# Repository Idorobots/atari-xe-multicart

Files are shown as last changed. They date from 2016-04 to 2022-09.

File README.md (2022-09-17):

# XE Multicart

A multi-game cartridge for the Atari 400/800/XL/XE with software game selection which can hold up to 127 games!

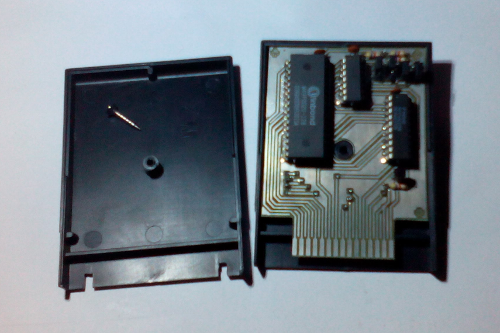
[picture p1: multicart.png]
multicart
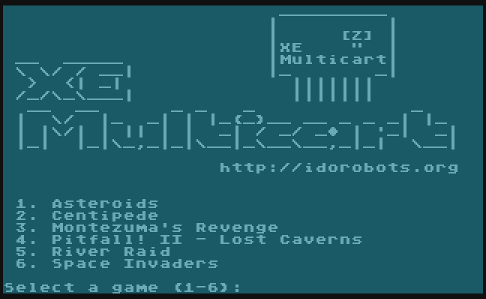
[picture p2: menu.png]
menu
 

# How it works?

A `74HCT373` latch is used for extra address pins, it's accessed by writing to the cartridge control block (`$DF00`) causing a bank switch. After selecting appropriate ROM bank, the firmare resets the console in turn starting the game. To select another game, reboot your Atari.

# Assembly instructions
## PCB
Assuming that you already have the PCBs on hand, either by ordering them on-line or creating them yourself, the assembly is pretty simple - just solder the `74HTC373` latch, the transistor and the passive components. It is highly recommended to solder a socket for the memory chip as it makes it much easier to re-program it. **Also, keep in mind that the component side goes into the console facing down, so prepare your case accordingly.**

## Memory chip configuration

The PCB layout of this cartridge is customizable - you can fit any 28/32-pin JEDEC-compliant EPROM chip in the `27C` line or compatible flash memory chip with size ranging from as low as 64 kbit up to 8 mbit. Fitting larger chips means you will be able to store more game ROMs (up to 127 total), but you can also use this layout without the game selection firmware to store any single standard 8k/16k game you want.

### Jumper settings

There are four jumpers on the PCB - `JP1` to `JP4` - oriented vertically when looking at the top layer with the edge connector facing down:

```
      0   0   0   0\ UP
DOWN /0   0   0   0/
     \0   0   0   0
     JP1 JP2 JP3 JP4
```

These are used to configure the cartridge for the appropriate memory chip. The following table lists jumper settings for various common configurations (UP means "short top two pins", DOWN means "short bottom two pins" and X means "don't care"):

| Memory chip size | JP1  | JP2  | JP3  | JP4  |
| --- | ---- | ---- | ---- | ---- |
| 64k (27C64) | X | X | UP | UP |
| 128k (27C128) | X | X | UP | UP |
| 256k (27C256) | X | X | UP | DOWN |
| 512k (27C512) | X | X | UP | DOWN |
| 1m (27C010) | UP | UP | X | DOWN |
| 2m (27C020) | UP | UP | DOWN | DOWN |
| 4m (27C040) | UP | DOWN | DOWN | DOWN |
| 8m (27C080) | DOWN | DOWN | DOWN | DOWN |

## Building the firmware
### Prerequisites
To succesfully build the firmware for the multicart, you will need to set up the following dependencies on your system:
- `make` - the Make build system,
- `python3` - Python programming language version 3.*,
- `gcc` - GNU Compiler Collection,
- `cc65`- the [CC65 compiler](https://cc65.github.io/).

### Build
In order to build the firmware & a cartridge image you will need some standard 8k/16k ROM files (obtainable freely on the Internet). Install all the dependencies, put your ROMs into the `roms/` directory and type:

```
make
```

This will run a script that automatically detects and arranges the games, builds the firmware and compiles a cartridge image ready for burning with your favourite EPROM burner.

Alternatively, you can supply a custom ROMs directory like this:

```
make ROMS=path/to/roms/directory
```

If you encounter any troubles while building, make sure to rebuild everything cleanly:

```
make clean && make
```
## Building from a docker container

In order to build the container itself run the following command in project directory

```
docker build -t atari_xe_multicart:latest .
```

After the container is ready to use run the following command to create `cart.bin` file. It assumes that .rom files are inside the /roms directory inside project directory.

```
docker run -ti --rm -v $(pwd)/roms/:/input/ -v $(pwd):/output/ atari_xe_multicart
```

# Running in an emulator

Multicart images don't work in any emulators that I know of, because they are using a custom (if simplistic) bank-switching mechanism. For testing purposes, you can run just the `menu.bin` (the game selection firmware) by loading it as a standard 8k cartridge ROM in your favourite Atari 800/XE emulator. For example:

```
atari800 -xl -xlxe_rom path/to/ATARIXL.ROM -cart menu.bin
```

It'll display the game selection menu, but any attempts at selecting a game will result in restarting the game selection menu.

# License

Software & hardware licensed under the MIT license (see LICENSE file for details). The OSHW logo comes from the [BFL library](http://www.baconfatlabs.com/2011/11/oshw-eagle-symbols-for-schematic-and-silkscreen/), licensed under CC-BY-SA. Any commercial product names seen on software screenshots are for demonstration purposes only and are not included with this product.

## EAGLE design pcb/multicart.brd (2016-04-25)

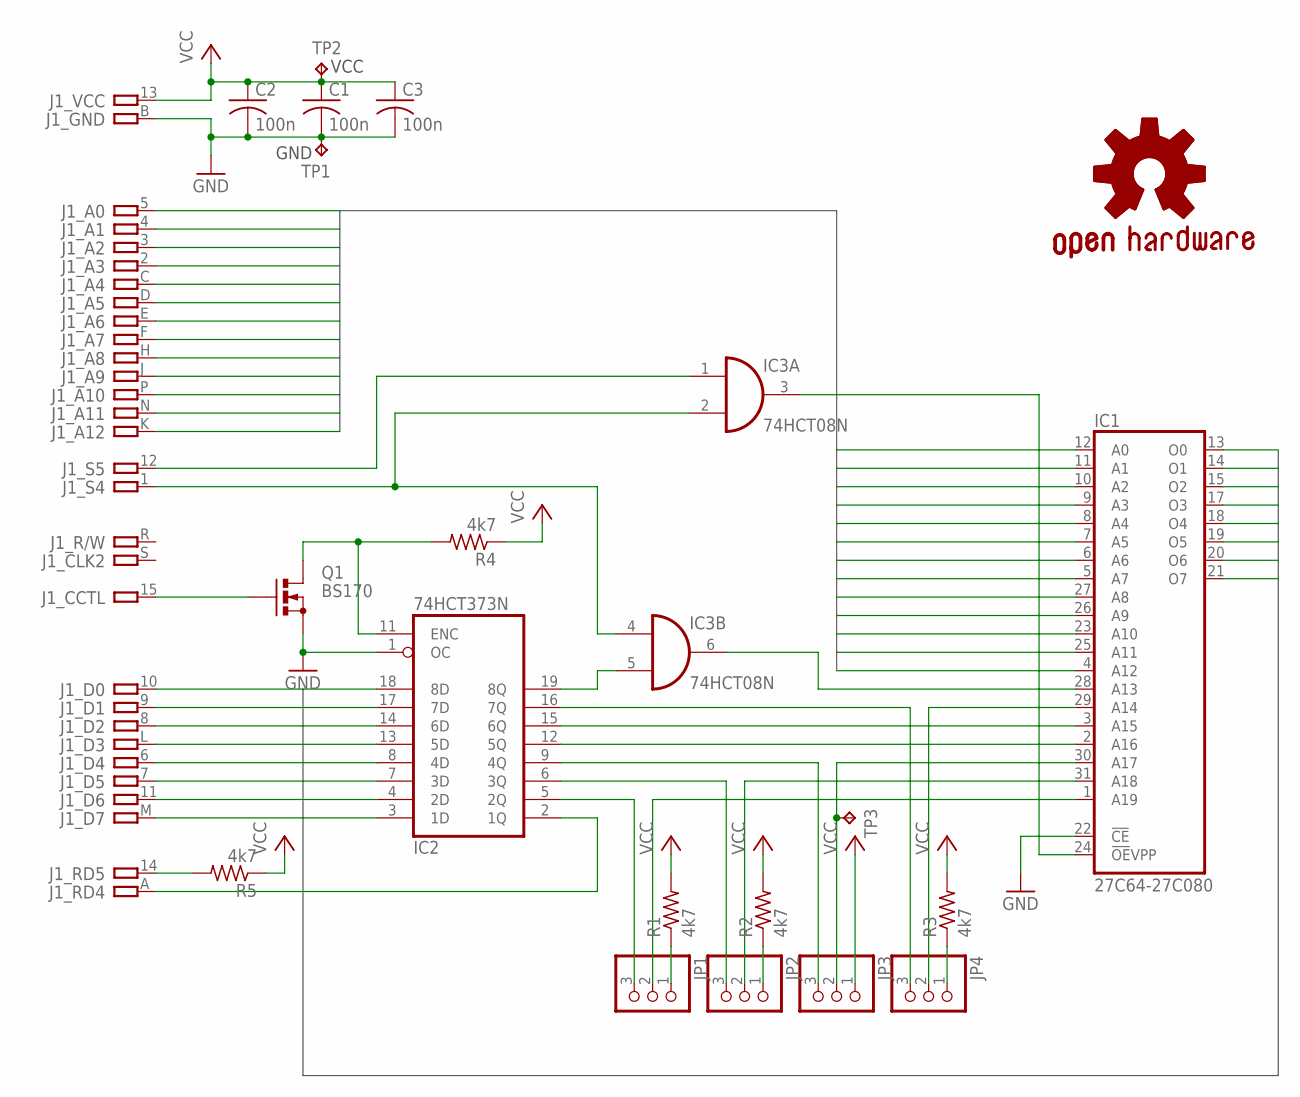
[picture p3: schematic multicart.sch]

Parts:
C1, C2, C3: 100n; C025-025X050
GOLD_ORB_SM1: OSHWLOGO_GOLD_ORB_SM; OSHW2
IC1: 27C64-27C080; DIL32
IC2: 74HCT373N; DIL20
IC3: 74HCT08N; DIL14
J1: ATARI-800
JP1, JP2, JP3, JP4: PINHD-1X3; 1X03
Q1: BS170; SOT54E
R1, R2, R3, R4, R5: 4k7; 0204/7
TP1, TP2, TP3: TPB1,27; B1,27

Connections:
A0: IC1.12 (A0), J1.5
A1: IC1.11 (A1), J1.4
A2: IC1.10 (A2), J1.3
A3: IC1.9 (A3), J1.2
A4: IC1.8 (A4), J1.C
A5: IC1.7 (A5), J1.D
A6: IC1.6 (A6), J1.E
A7: IC1.5 (A7), J1.F
A8: IC1.27 (A8), J1.H
A9: IC1.26 (A9), J1.J
A10: IC1.23 (A10), J1.P
A11: IC1.25 (A11), J1.N
A12: IC1.4 (A12), J1.K
D0: IC1.13 (O0), IC2.18 (8D), J1.10
D1: IC1.14 (O1), IC2.17 (7D), J1.9
D2: IC1.15 (O2), IC2.14 (6D), J1.8
D3: IC1.17 (O3), IC2.13 (5D), J1.L
D4: IC1.18 (O4), IC2.8 (4D), J1.6
D5: IC1.19 (O5), IC2.7 (3D), J1.7
D6: IC1.20 (O6), IC2.4 (2D), J1.11
D7: IC1.21 (O7), IC2.3 (1D), J1.M
GND: C1.2, C2.2, C3.2, IC1.16 (GND), IC1.22 (!CE), IC2.1 (OC), IC2.10 (GND), IC3.7 (GND), J1.B, Q1.S, TP1.TP
unnamed: IC2.19 (8Q), IC3.5 (I1)
unnamed: IC2.16 (7Q), JP4.3
unnamed: IC1.3 (A15), IC2.15 (6Q)
unnamed: IC1.2 (A16), IC2.12 (5Q)
unnamed: IC2.9 (4Q), JP3.3
unnamed: IC2.6 (3Q), JP2.3
unnamed: IC2.11 (ENC), Q1.D, R4.2
unnamed: J1.15, Q1.G
unnamed: JP1.1, R1.1
unnamed: IC1.31 (A18), JP2.2
unnamed: JP2.1, R2.1
unnamed: IC1.30 (A17), JP3.2, TP3.TP
unnamed: IC1.1 (A19), JP1.2
unnamed: IC2.5 (2Q), JP1.3
unnamed: IC1.29 (A14), JP4.2
unnamed: JP4.1, R3.1
unnamed: J1.14, R5.2
unnamed: IC3.1 (I0), J1.12
unnamed: IC3.2 (I1), IC3.4 (I0), J1.1
unnamed: IC1.28 (A13), IC3.6 (O)
unnamed: IC2.2 (1Q), J1.A
unnamed: IC1.24 (!OE!VPP), IC3.3 (O)
VCC: C1.1, C2.1, C3.1, IC1.32 (VCC), IC2.20 (VCC), IC3.14 (VCC), J1.13, JP3.1, R1.2, R2.2, R3.2, R4.1, R5.1, TP2.TP

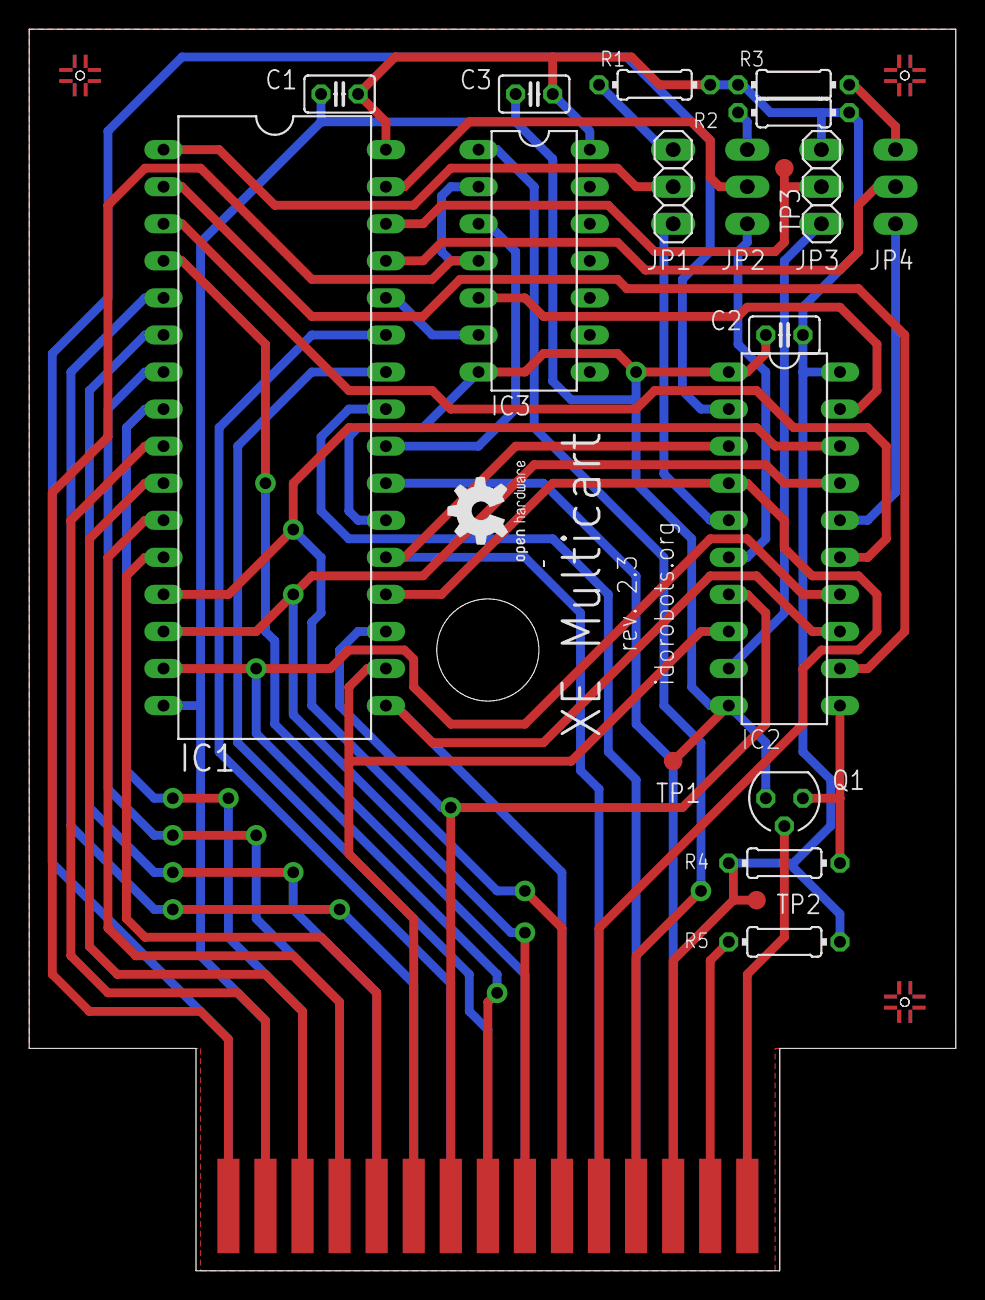
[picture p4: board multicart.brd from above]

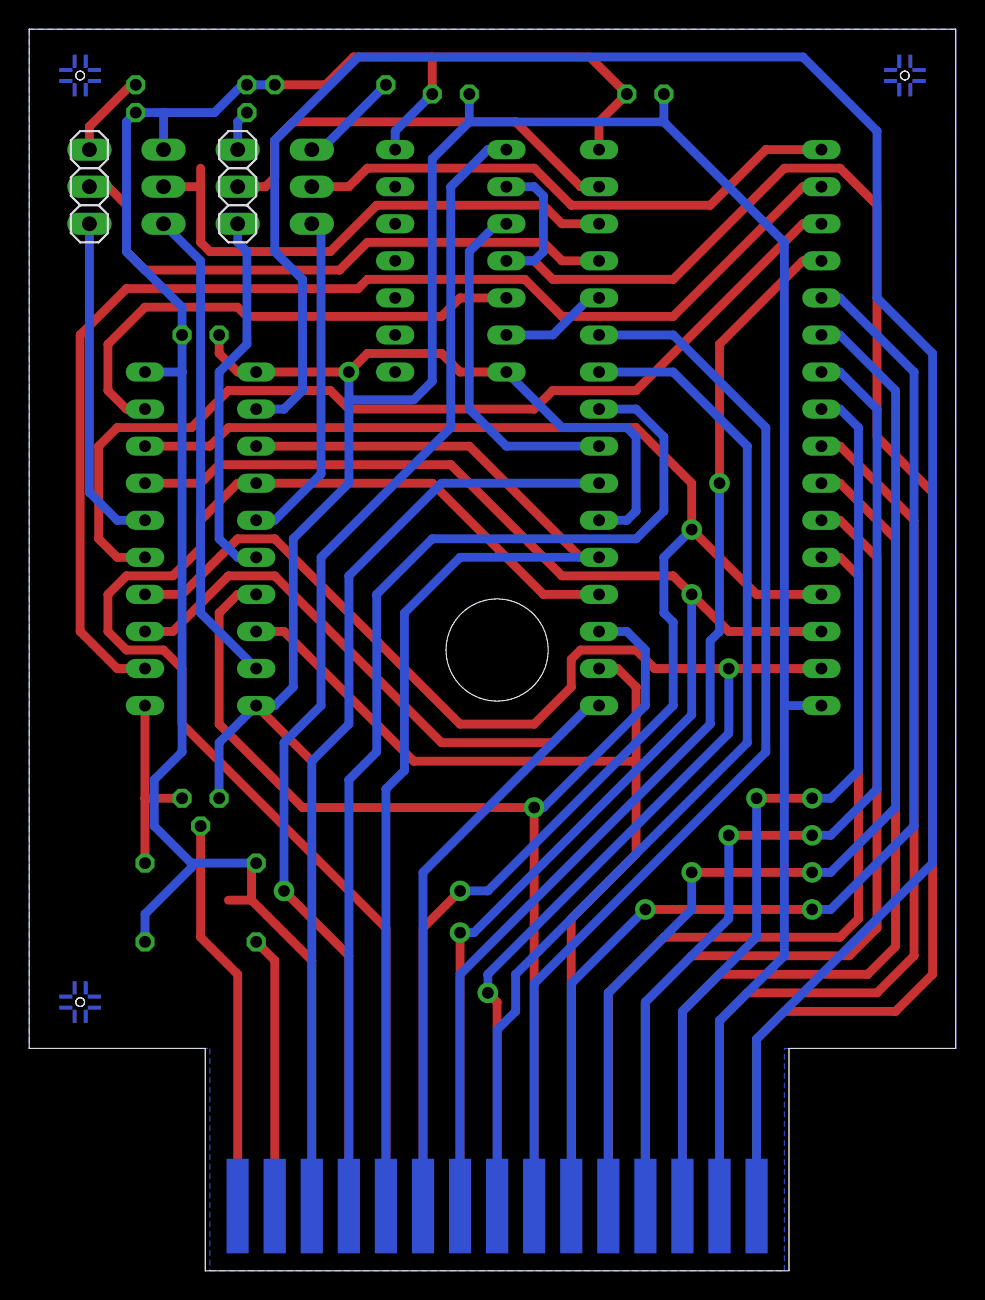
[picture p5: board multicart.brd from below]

Board: 2 copper layers, 63.5 x 85.1 mm, 27 parts (5 on the bottom side), 45 nets.

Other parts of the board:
U$1, U$2, U$3, U$4, U$5, U$6: PASSER-HOLE

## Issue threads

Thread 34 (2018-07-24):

How to setup 27c512 ?

emartisoft, 2018-07-24:
Hi,
I wanted to use 27c512 but how to setup it on pcb. Please look at the my uploaded picture. Is this true? I created 64 KB bin file on linux via make command. I tried it on 600xl and 800xl but it does not work.

How to do? What stage could I have done wrong?

http://i64.tinypic.com/2nip4s7.jpg

Idorobots, 2018-07-26:
Hi,

The setup looks good, that should result in a 512k multicart and assuming that the bin file begins with the game selection firmware it should work on any XE-series machine. Not sure about XL as these probably use a slightly different OS ROM, which the game selection firmware kind of takes for granted right now.

Does it display anything when you put the multicart into the console? Can you try burning an 8k game to the very beginning of the flash chip, so that it acts as the selection firmware? If that does work it's probably the firmware that needs some adjustments. Unfortunately, I don't have any non-XE Atari machines to test in on :(

You can also try fiddling with the jumpers, basically any setup should at least display the game selection firmware, so if that doesn't change anything it's probably something different.

Also, a silly question - are you inserting the multicart into the console correctly? It should go there component side down (a bit counterintuitive, I know).

Idorobots, 2018-07-26:
I just realized that the staged photo is misleading as it looks like the component side goes on top, not the bottom. I'll make that explicit in the README.

emartisoft, 2018-07-26:
Hi again,
Thank you firstly. As I said, I tried & tested it on ATARI 800XL & 600XL but not XE series :(

I burned 8K rom file (for Your menu.rom and a few 8k game rom file) on M27C64A. I tested it all. When I put the cart into the console, It displays like my uploaded photo image.

_Image Links:_
I. http://i68.tinypic.com/34ye83d.jpg
II. http://i63.tinypic.com/289g552.jpg

If I insert the multicart into the console wrongly, It boots BASIC, It says READY. :)

As a result should we say that it does not work for XL?

Idorobots, 2018-07-27:
That might indeed be the case here, unfortunately.
It's hard for me to say what might be the issue here without hooking up a signal analyser to the cart, so I can't recommend anything other than maybe reflowing all connections on the cart PCB and cleaning the cart slot contacts on the console. I did get a lot of odd behaviour resembling your second picture in the previous reply when building this thing - the problem was bad connections between the thin PCB of the multicart and the cart slot on my Atari. So maybe that's indeed the case here? A 1.6 mm thick PCB should be fine, but maybe you've ordered 0.8 mm?

Idorobots, 2018-07-27:
Looking at my old version in the picture in the README I actually went for using an HC series 74373 latch instead of a TTL one. I don't really remember that changing much, but since I left out any pulldowns on the extra address lines comming from the 74HCT373 it might be the root cause of the issue - the lines aren't all zeros making it select one of the ROMs already. Potentially a non-existant one or the wrong half of one of them. Maybe try changing that for a 74HC373 instead? I'm also using a TTL 7408 and the transistor is a BS107.

emartisoft, 2018-07-27:
I have ordered 1.6 mm thick PCB. I will reflow all connections on the cart PCB and cleaning the cart slot contacts on the console.

I will try 74HC373. But You said that transistor is a BS107. **It is BS170, isn't it?**
If I change from 74HCT373 to _74HC373_, Should I use _TTL 7408_ and _BS107_?

Idorobots, 2018-07-27:
On the working cart I have a `74HCT08`, `74HC373` and `BS107`, but the `BS170` should do equally fine. I don't have a `74HCT373` on hand right now, so I can't really test if that causes the odd behaviour. I suppose it would be wise to add the pulldowns to the design regardless.

emartisoft, 2018-07-27:
Hmmmm. I also will try `74HCT08`, `74HC373 `and `BS107`. I'll return feedback to you.
In addition, Is **LS** (`74LS08`, `74LS373`) slow or compatible for this project?

emartisoft, 2018-08-01:
I tried LS but it does not work. :(

Idorobots, 2018-08-01:
Then the HCT probably won't work either. That's a pickle, as I can't really reproduce the problem on my end, so I can't really debug it. All I can think of doing is hooking a logic analyser to the extra address lines to verify wether the transitions are correct.

LessNick, 2022-03-23:
Hello there ;)

Finally, I finished soldering my board and I also have questions.

I also want to use the w27c512 chip, but I have questions about how to place the chip in the socket?
Unfortunately, the links to the photos of the topikstarter are no longer available, and the answers did not bring clarity.

Since it is correct to place the chip in the socket, from the beginning of the contacts or from the end?

Here my photos: https://imgur.com/a/wgHHUli

Also, do I understand correctly that you need to insert the cartridge into the atari with the chips down?

I absolutely don't mind if you add my photos to the project so that in the future people can get visual information right away.

Thank you very much in advance!

Idorobots, 2022-03-26:
Hi, sorry for the late answer.
The chips supported are conformant to the JEDEC pinout standard, meaning you can align them towards the bottom of the socket (away from the notch). Then you have to set up the jumpers accordingly (it's described on the README) in order to supply the power to the chip.
If you're unsure how to align the chip, you can follow the pinout on the biggest one supported ([see this datasheet](https://pdf1.alldatasheet.com/datasheet-pdf/view/56131/ATMEL/27C080.html) and align the GND & Output3 pins on your chip with the socket.

LessNick, 2022-03-26:
Oh! Thanks for anwser! As I understand it, this is the same principle as in the programmer. There, too, the chip is aligned to the bottom of the connector.

Like on this photo → https://imgur.com/a/GS2mEZp

Pins set for 512Kb:

Memory chip size | JP1 | JP2 | JP3 | JP4
512k (27C512)    |  X  |  X  | UP  | DOWN

The question of how to correctly insert an atari cartridge also remained open. Is the previous photo correct?

Location down the chips → https://imgur.com/a/wgHHUli

Idorobots, 2022-03-26:
Looking good! According to the README the component side is supposed to face down when inserted into the console. I'm inclined to believe that's correct :D

LessNick, 2022-03-26:
Unfortunately, the board didn't work :( Atari starts polling devices and freezes. If the cartridge is removed, atari start BASIC.

How i understand that when start the cartridge, there should be no device polling. Just starts the code from cartridge?

Idorobots, 2022-03-26:
Yup, it should run the cart code instead of basic. I had some contact issues initially, because my PCB was too thin. You might wanna check the connections on yours. In my case, either bending some of the Atari edge connector pins or slightly tinning the contacts on the multicart was what did the trick.

LessNick, 2022-03-26:
Ah, here's the thing. Thanks a lot. I'll check the contacts on atari.

gadiscz, 2022-04-06:
Hi, I have the same problem. I have an Atari 800 XL. I made a XE Multicart cartridge (27C512), I did everything according to the instructions, but my menu doesn't appear and I just run basic READY.   :-(
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
LessNick, 2022-04-06:
Unfortunately, cartridge has not start. I cleaned the contacts on the atari side. Distinct black traces of oxides remained on the paper. I ordered the board on allpcb.com and its thickness is really 1.6mm.

The ROM chip is working, it can be flashed and read without problems.

There are only two questions left, these are the other chips themselves, perhaps the Chinese sent low-quality components. And secondly, capacitors near chips confuse me a little. If I understand correctly, this is for more stable works of chips and capacitors should not be polarized?

Judging by the scheme, they can be both polarized and fixed. I use fixed.

gadiscz, 2022-04-06:
I have a thickness of 1.6 mm. other original old cartridges work for me. I will try another EPROM size

LessNick, 2022-04-06:
>I will try another EPROM size

Hmm... maybe that's really the problem. Looking forward to the result :)

Idorobots, 2022-04-06:
> If I understand correctly, this is for more stable works of chips and capacitors should not be polarized?
These are bypass caps, they indeed make for a stable power supply for those chips. You can use small-value tantalums or ceramics for these, the values don't really matter so anything from 1nF to 100nF should be good enough.

> I have a thickness of 1.6 mm.
Hmm, then it's going to be the multicart indeed. Please check the 7408 next, that one is used to determine whether the EPROM should be enabled and which address to choose for it. If that works correctly then it means the EPROM is not floating, so it should at least execute something other than BASIC (even if it's some garbage).
Another thing to check is the MOSFET inverter on the CCTL line, that controls the bank selection. If that is stuck in either state (due to a different pinout of the part you used for your multicart, or some such problem) it might cause the data lines to be pulled high or low and that might mess it up (although I would expect it to execute some garbage instead of BASIC if that were the case).
Lastly, it might be the software. AFAIR, I'm doing some "sanity checks" to figure out if the console was soft-rebooted to start a new game - poking around the OS memory to check some values in memory. Perhaps that is triggered by the menu immediately due to a different OS version than the one I implemented it on. You can try programming the EPROM with just one game at the very start of the EPROM (so instead of the game selection menu) and try the multicart this way. If that's it, then we'll need to figure out how to update sanity checks for different OS versions.

gadiscz, 2022-04-06:
Ok I'll try to upload one file. How do you convert .xex files that are different size 6-40kB to the correct size (8-16kB)?

LessNick, 2022-04-06:
>How do you convert .xex

No no! XEX file will not work, you need to take a ready-made BIN file, not even CAR (it has a header at the beginning of the file)

LessNick, 2022-04-06:
I report. I flashed one image of the Boulder Dash cartridge in W27c512 - the result is the same, that is, none.

Then I found very old chips with ultraviolet erasure 27c512, 27c256 and 27c64. I did not try to flash them, since they must first be washed with an ultraviolet lamp. I just plugged it in for a test, setting the jumpers according to the diagram.

256 and 512 the result is the same as with rom image. But 27s64 began to flickering the screen, then purple then black. That is, it looks like something is still trying to start.

A little later I will try to erase the chip with ultraviolet light and re-flash it.

LessNick, 2022-04-06:
I also tried to run without a ROM, the result is the same, nothing happens. It is very likely that some components of scheme do not work and the ROM chip does not turn on correctly.

I would venture to suggest that for 27c64 such switches are not critical and it is trying to start.

gadiscz, 2022-04-06:
What program do you use to convert xex to rom? Do you need to enlarge a file that has 15kB to 16kB?

gadiscz, 2022-04-06:
I have this working but only with their file...

[https://www.pcbway.com/project/shareproject/ATARI_800XL_MULTI_GAME_CARTRIDGE__4_x16KB_.html](url)

gadiscz, 2022-12-21:
finally i bought an atari 800XE but the problem is not solved :( still my bin files don't work. i have different eproms do you have a working bin file for test?

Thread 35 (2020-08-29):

Cart detection

dikdom, 2020-08-29:
Hello,
could you please describe how an Atari XL/XE detects if a cart is present in the system? I thought it triggers a low /S4 and checks if RD4 is high (and respectively triggers /S5 and checks RD5) but in this case the 373 provides random output after poweron, so it should not work... 👍  (but it does at your end).

Thanks!
Erm... RD5 is always set high, so I guess the machine triggers /S5 and RD5 is high -> cartridge is present.

Idorobots, 2020-08-29:
Hi, indeed, whenever the cart is in the slot it'll register as present. The 373 goof up is known, surprisingly I had some good luck with TI parts always coming on in a known state, so I never noticed that originally. I don't have an Atari on hand these days, so I never bothered fixing the issue. :) A generally better idea would be to use a latch with master reset, as to ensure a proper state after startup.

Closed 2020-08-29.

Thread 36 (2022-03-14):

Emulation support

LessNick, 2022-03-14:
Hello.

At my request, Beta version of Altirra now supports "xe-multicart".

I created two cartridges with 8k games and 16k games.

In the first case (8k) everything works fine. But the cartridge with 16k games could not be start. The emulator crashes or atari show self test. Unfortunately, Unfortunately, I'm only in the process of soldering a hardware cartridge so far and can't test rom image at the real atari.

So far, of course, this is still only a beta version, but it is already gratifying that you can test the assembly before flashing the chip.

Perhaps this is some kind of flaw in the emulator, or perhaps I have not assembled something correctly.

In any case, I wanted to inform you about this wonderful news. As soon as full-fledged work in the emulator is implemented, it will be possible to update the documentation.

Link to the post

https://atariage.com/forums/topic/327133-altirra-400-released/?do=findComment&comment=5021103

Idorobots, 2022-03-14:
Hi,

This is as much a good news as it is surprising, since this project has been pretty inactive for the past few years. :)
If I remember correctly, the 16k games need to be aligned a certain way in order to load correctly (essentially, both 8k halves have to occupy the right memory locations). That alignment is supposed to be done by the packing scripts provided in this repository, but I've got to admit that I haven't tested them thoroughly - I made some carts with the games I like the most and that seems to be working on both of my machines.
Would you like to become a contributor to this repository? I currently don't have the time to maintain it, and it seems like the Atari community is actually using this thing. :)

LessNick, 2022-03-14:
Well, at the moment I'm interested in this project. I ordered PCBs and plan to solder a few pieces. In any case, if there are any improvements or changes in the code, I will definitely send you :)

LessNick, 2022-03-14:
I was able to find the pattern of the error.

If you arrange the blocks like this:
8k menu
8k first game
16k second game

For example, pac-man = 8k. zaxxon = 16k
Everything works perfectly.

I think we need to rewrite a bit the logic of the collector in accordance with this idea.

By the way, another passing question, cartridges with a volume of more than 16k, for example 32k, is not really possible to combine at all?

Idorobots, 2022-03-14:
Hey,

Hmm, yeah, I think the menu needs to be on one of the slots during boot so the other one cannot be taken by a 8k game, if the first game is 16k it skips that slot so it's all fine.

32k carts use a mapping scheme of their own as the Atari only has two cart slots 8k memory each. 8k games can go into either of the slots, while the 16k games occupy both of these. The bigger carts need some extra hardware to switch different parts of the cart in and out onto these two slots (much like the XE multicart does it). I don't think the scheme I chose is compatible with any existing cart designs (this project started on a weekend, so I didn't do much research). :)
I think with some hardware modifications it should be possible to make it compatible with at least some cart types - AFAIR the XEGS cart for instance follows a similar bank switching scheme.

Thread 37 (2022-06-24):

How to generate the compiled bin to program?

repetto74, 2022-06-24:
Hi,
I am struggling in trying to understand how to generate a compiled bin file with my rom selections and menu.
I am using Windows10 and try to use "make" command from the console but it does not work. I tried with buildcart.py and I get the message that no roms have been found despite 8k and 16k roms are copied in the roms folder.
Is there a more detailed guide on steps to perform here? What need to be installed?
Thanks
Rick

Idorobots, 2022-06-25:
Hi, I don't currently have access to any windows machines, but if memory serves me right, there were pre-made unix-like development environments available for Windows. MinGW and Cygwin are two such examples, but there is also the newly added Windows Subsystem for Linux that should also support makefiles via an external program (see [here for more info]( https://stackoverflow.com/questions/32127524/how-to-install-and-use-make-in-windows)).
Once you have either of those set up, it should be a matter of just placing your ROM files into the `roms` directory and then running the make command.

repetto74, 2022-06-25:
Hi Idorobots,
Thank you for your reply :-). I will give a look to your link at try to figure out how to install a proper working environment to compile under Windows 10.
Have a good day!
Rick

repetto74, 2022-07-01:
I have installed Make on Windows 10. When I try to compile I get this message from the CMD console:
```
C:\Users\RICCARDO REPETTO\Desktop\atari-xe-multicart-master>make clean && make
rm -f src/games.c
process_begin: CreateProcess(NULL, rm -f src/games.c, ...) failed.
make (e=2): Le fichier spécifié est introuvable. --file not found--
make: *** [clean] Error 2
```
What am I doing wrong here?

Idorobots, 2022-07-01:
Yeah, that's my sloppy Makefile complaining that it can't clean the intermediate files, because they don't exist :) You can skip the `make clean` call and go directly to `make`. That should create the files and compile a binary blob for you to flash on the EEPROM.

repetto74, 2022-07-01:
Unfortunately same with make command

```
C:\Users\RICCARDO REPETTO\Desktop\atari-xe-multicart-master>make
./buildcart.py --config --output src/games.c roms/*
process_begin: CreateProcess(NULL, env python3 C:\Users\RICCARDO REPETTO\Desktop\atari-xe-multicart-master\buildcart.py --config --output src/games.c roms/*, ...) failed.
make (e=2): Le fichier spécifié est introuvable.
make: *** [src/games.c] Erreur 2
```

Idorobots, 2022-07-04:
Looks like the Python3 binary is missing. There's a little script that glues the ROMs together written in Python that runs during the build process. I think installing Python3 should fix that one. :)

Idorobots, 2022-07-04:
Added all the dependencies that need to be set up to the README, next to python3, you'll need the [CC65](https://cc65.github.io/) compiler some other stuff.

repetto74, 2022-07-04:
Thanks for the explanations :-)
I have installed already the CC65 and set-up the variable parameters to use it via the console prompt but maybe the path is not pointing to the folder for Atari XL source.
For Python3 it is weird because i have already a Python3.7 release installed on Windows10 unless I need to have only version 3.0.
Still continuing with some trials then :-)

Idorobots, 2022-07-04:
Python 3.7 should be fine. Is it accessible from the environment you run Make from? If not, then probably the PATH variable (or whatever Windows is using for the same purpose) needs to be adjusted.

repetto74, 2022-07-04:
You are totally right ! :-). Although I have Python 3.7 installed I did not set the path variable!
I will set it up and hopefully it should work now :-)
make, gcc and cc65 are already installed and set-up.

repetto74, 2022-07-08:
Back again with bad news. Unfortunately I get the same error even after setting variable parameters for the Python executable. Is there any chance to have at least a testing bin that I can program to check if the multicart is working?

Idorobots, 2022-07-08:
Hi, attached the menu.bin in a zip. It should be runnable on any emulator as a standalone cart, and it can be programmed on the multicart without any games. I think it'll still list some selection, but then it'll execute some garbage that is on the eeprom instead.

[menu.zip](https://github.com/Idorobots/atari-xe-multicart/files/9074546/menu.zip)

repetto74, 2022-07-08:
Thanks, I will give it a try :-). And hope I can figure out how to set-up the environment to compile properly :-)

repetto74, 2022-07-08:
Menu works on the emulator so I will confirm the multicart is ok on a real 800XL :-)

repetto74, 2022-07-09:
Well it is a total fail for me :(. Programmed a 27c040 with the menu.bin and set the jumpers but all I get is a red screen at startup. Tried with a Winbond 27c020 + jumper settings but same result on screen.
Checked both 74HCT08 and 74HCT373 and they are reported good by the TL866 programmer. Checked continuity on jumpers and all is ok.
Tried the 800XL with a genuine cartridge and working fine.
Bad luck here :-(.

Idorobots, 2022-07-09:
Hmm, that's an oddly consistent thing to happen for a random garbage in the memory.  It should be possible to put any 8k ROM in the start of the eeprom and then the multicart should behave exactly like a regular 8k cart. Can you please see if that happens to work?

repetto74, 2022-07-09:
Yes, I will burn any 8k game info the eprom and test it :-)
Keep you posted !

repetto74, 2022-07-10:
Bad news again unfortunately :-(. I burned galaxian (8k) onto the eprom but still the same issue with just garbage color on screen.
I have tested the BS170 mosfet as being good between G,S and D. I am trying to narrow down possible hardware issues here and I can only think about 2 things:

- the 2 IC logics are rebranded ones(got them from Aliexpress) and could be LS instead of HTC (thus the programmer is checking both of them correctly). I do not know how much this can have an impact on the hardware.
- The socket of the 74HTC08 is maybe bad and gives intermittent connectivity (I do not like some of the pins and I will change it).
For the rest I really do not see where the issue may be.

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

Idorobots, 2022-07-12:
Hmm, hard to tell what's going on in here. I no longer have a multicart or an Atari on hand to try to help you troubleshoot, but judging by the schematic it should be possible to only populate the EEPROM and the 7408 to get a dumb one game cartridge. There is a known problem with this design and some 74373 parts that produce a random garbage on the outputs when they power up which is messing up the menu startup. Perhaps that's what you're running into as well?
I never came across this problem back when I made this multicart design and I think I was using TI parts for mine.

repetto74, 2022-07-12:
Indeed really a puzzling issue here.
Tried to remove the 74373 and same red screen.
I will replace the socket of the 74LS08 and also try the multicart on a spare 600Xl I have in order to check if it is not due to incompatibility with my 800XL. If no luck then I will put this cart aside and move to something else :-).

Idorobots, 2022-07-12:
The only other thing I can think of is the EEPROM. Multicart accepts different JEDEC EEPROM sizes and there are jumpers there for the VCC supply pin. I assume your chip is conformant to the JEDEC pinout and is getting the VCC and GND connections. Perhaps you set up the other address pins high via the jumpers and now it's executing something from the EEPROM, but not on the 0 address?

repetto74, 2022-07-13:
How can I make sure the eprom is JEDEC compliant? It is branded AM27C040 and programs as expected with programmer settings to AM27C040. I have tried also a Winbond 27C020 with same result. Jumpers are set on the board as per the instructions so I assume this is ok.
27c040 - J1 UP, J2 DOWN, J3 DOWN, J4 DOWN

Idorobots, 2022-07-13:
According to its datasheet it is compliant, the jumper settings are also correct. Short of hooking up a logic analyzer and checking what's going on directly on the cart bus, I'm out of ideas at this point. :(

repetto74, 2022-07-13:
Let me replace the socket of the 74LS08 to be on the safe side. I will then try to troubleshoot further :-)
Thanks for you help!

repetto74, 2022-09-16:
Just to close this topic.
I have replaced the suspicious socket but still multicart not working :-(.
It can be any as maybe just a faulty PCB manufacture but to much assle. I will move to the Unocart  and have it built as soon as I'll get PCBs and components :-)

Idorobots, 2022-09-16:
I'm sad to hear. :( Good luck with the Unocart!

Closed 2022-09-16.

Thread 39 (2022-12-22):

Does it work for anyone?

gadiscz, 2022-12-22:
I tried different eproms, different 8.16kb files and just the menu and it never worked. I tried to put the eprom into another cartridge and the menu appears there at least. So does it work for anyone?

gadiscz, 2022-12-22:
I have a different pcb from the same company and it works, even your menu starts there without the game.  what can i try  do you have your working bin file?  I tried different eproms and just the menu.  I have two boards made and neither one works.

gadiscz, 2022-12-23:
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

gadiscz, 2022-12-23:
I used M2764A where I only have the menu loaded.  on another board I can see it, I can see the menu, but not on this cartridge :(

Idorobots, 2022-12-23:
Hmm, yeah, looks pretty nice. If the menu loads on another cart board then it should be operational (that part work just like a normal cart does), so it'll be the PCB that's not working. Silly question, but it might very well be my goof up - are the square (oh god) vias between layers all connected? On my prototype I didn't have any way to metalize the via channel, so I went with a short wire and soldered it on both sides to make a connection - perhaps the board file doesn't actually specify these as vias, but instead just one sided pads?

Idorobots, 2022-12-23:
The other thing I can think of is that Q1 - AFAIR I went with one of those NPN signal mosfets, but I might have put a bipolar on the schematic which might not be correct. Sorry, it's a bit fuzzy after all these years and I don't have the prototype cart anymore.

gadiscz, 2022-12-23:
pcb board is made professionally.  the holes are connected.  So should I try another transistor?

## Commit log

2016-04-04 Added schematic of the multi-cart.
    [multicart.sch]
2016-04-04 Changed cart connector package & removed unused signals.
    [multicart.sch]
2016-04-04 Added PCB layout of the multicart.
    [multicart.brd]
2016-04-04 Added a stub of the game selection software.
    [menu.cfg]
2016-04-05 Swapped cart bank mapping & reorganized the PCB.
    Fixes #1
    [multicart.brd, multicart.sch]
2016-04-05 Optimized the design.
    [multicart.brd, multicart.sch]
2016-04-05 Added bypass caps to the design.
    [multicart.brd, multicart.sch]
2016-04-06 Modified the design to support both 8k and 16k standard games.
    [multicart.brd, multicart.sch]
2016-04-07 Removed the RD5 line resistor.
    [multicart.brd, multicart.sch]
2016-04-07 Optimized the design a little.
    [multicart.brd]
2016-04-07 Added pull-downs to the CCTL & R/W lines.
    [multicart.brd, multicart.sch]
2016-04-08 Optimized the design by using AND gates.
    [multicart.brd, multicart.sch]
2016-04-10 Updated the schematic to support 8-mbit flash chips.
    [multicart.sch]
2016-04-10 Updated the PCB design.
    [multicart.brd, multicart.sch]
2016-04-10 Optimized the PCB design.
    [multicart.brd, multicart.sch]
2016-04-12 Added some sparkles to the PCB layout.
    [multicart.brd]
2016-04-12 Added OSHW logo to the PCB & the schematic.
    [multicart.brd, multicart.sch]
2016-04-14 Added test points for power.
    [multicart.brd, multicart.sch]
2016-04-14 Vectorized silkscreen fonts.
    [multicart.brd]
2016-04-14 Turned alignment vias into full-fledged holes.
    [multicart.brd]
2016-04-14 Adjusted the PCB dimension for manufacture.
    [multicart.brd]
2016-04-14 Adjusted some traces for manufacture.
    [multicart.brd]
2016-04-14 Removed trademarks from the project.
    [multicart.brd]
2016-04-14 Updated the design to fit into a Z7 cart case.
    [multicart.brd, multicart.sch]
2016-04-15 Increased the via drill size.
    [multicart.brd]
2016-04-15 Used proper alignment markers instead of vias.
    [multicart.brd]
2016-04-16 Moved the board to match the origin.
    [multicart.brd]
2016-04-19 Adjusted the board dimensions to better fit into a Z7 case.
    [multicart.brd]
2016-04-19 Adjusted trace widths to make home etching easier.
    [multicart.brd]
2016-04-22 Added a prototype picture.
2016-04-25 Added a safety resistor to the RD5 line.
    This makes it harder to break stuff when the cart is inserted upside
    down.
    [multicart.brd, multicart.sch]
2018-02-06 Updated the linker config for the latest cc65.
    [menu.cfg]
2018-07-26 Made explicit notion of the PCB orientation when inserting the cart into the console.
